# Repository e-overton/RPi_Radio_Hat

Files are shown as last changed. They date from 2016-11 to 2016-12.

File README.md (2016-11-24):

Raspberry Pi B+ Radio Hat
============================
This board adds two AWA24S 2.4GHz DSS radio modules to the Raspberry Pi to enable remote control using radio-controller-like standards. In addition a real time clock is added to the board to keep track of time in a battery powered project.

This proect is based on the RPi template from: https://github.com/xesscorp/RPi_Hat_Template

Note this board is in development, and has not been fabricated/tested.

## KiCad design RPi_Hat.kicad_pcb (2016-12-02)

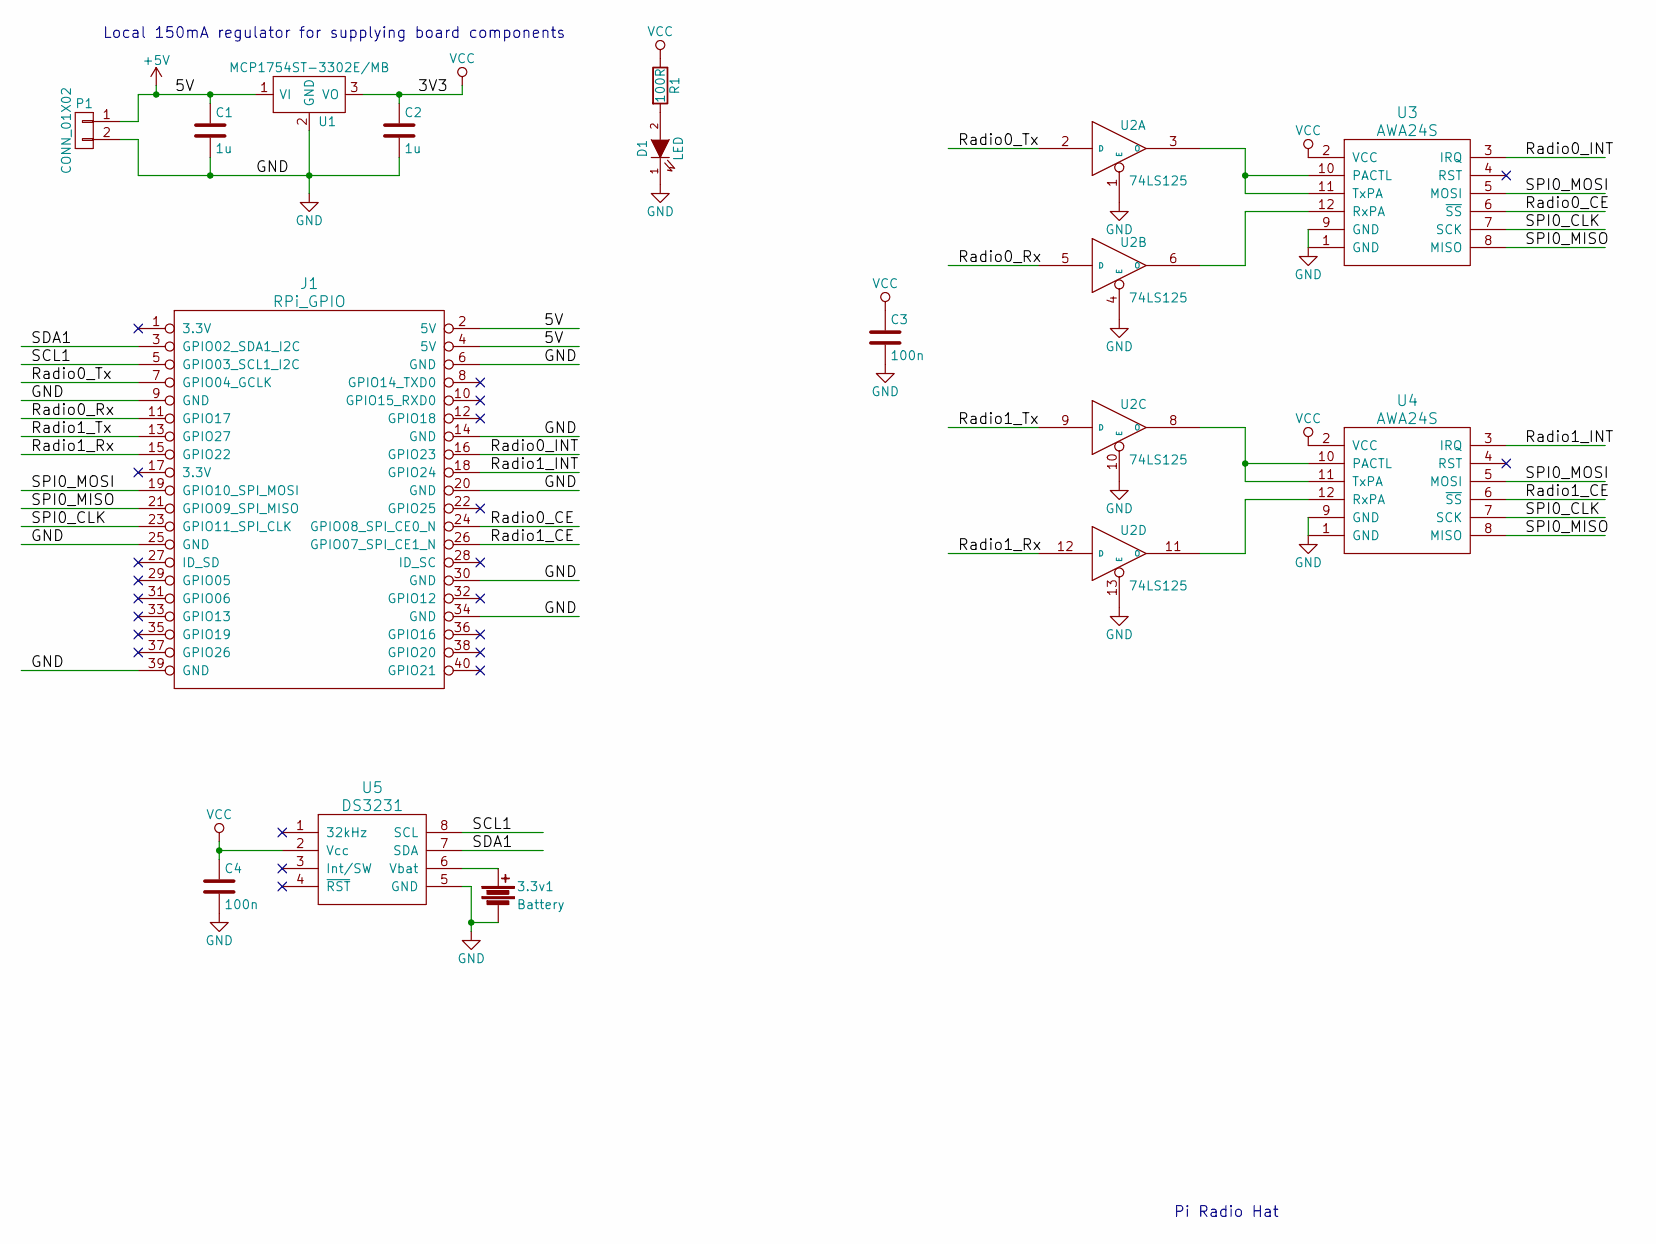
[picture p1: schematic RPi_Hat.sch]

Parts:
3.3v1: Battery; cr1225
C1, C2: 1u; C_1206
C3, C4: 100n; C_1206
D1: LED; LED_1206
J1: RPi_GPIO
P1: CONN_01X02; Pin_Header_Straight_1x02
R1: 100R; R_1206_HandSoldering
U1: MCP1754ST-3302E/MB; SOT-223
U2: 74LS125; SOIC-14_N
U3, U4: AWA24S
U5: DS3231; SOIC-8_3.9x4.9mm_Pitch1.27mm

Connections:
+5V: C1.1, J1.2 (5V), J1.4 (5V), P1.1, U1.1 (VI)
/Radio0_CE: J1.24 (GPIO08_SPI_CE0_N), U3.6 (~SS)
/Radio0_INT: J1.16 (GPIO23), U3.3 (IRQ)
/Radio0_Rx: J1.11 (GPIO17), U2.5 (D)
/Radio0_Tx: J1.7 (GPIO04_GCLK), U2.2 (D)
/Radio1_CE: J1.26 (GPIO07_SPI_CE1_N), U4.6 (~SS)
/Radio1_INT: J1.18 (GPIO24), U4.3 (IRQ)
/Radio1_Rx: J1.15 (GPIO22), U2.12 (D)
/Radio1_Tx: J1.13 (GPIO27), U2.9 (D)
/SCL1: J1.5 (GPIO03_SCL1_I2C), U5.8 (SCL)
/SDA1: J1.3 (GPIO02_SDA1_I2C), U5.7 (SDA)
/SPI0_CLK: J1.23 (GPIO11_SPI_CLK), U3.7 (SCK), U4.7 (SCK)
/SPI0_MISO: J1.21 (GPIO09_SPI_MISO), U3.8 (MISO), U4.8 (MISO)
/SPI0_MOSI: J1.19 (GPIO10_SPI_MOSI), U3.5 (MOSI), U4.5 (MOSI)
GND: 3.3v1.2, C1.2, C2.2, C3.2, C4.2, D1.1 (K), J1.6 (GND), J1.9 (GND), J1.14 (GND), J1.20 (GND), J1.25 (GND), J1.30 (GND), J1.34 (GND), J1.39 (GND), P1.2, U1.2 (GND), U1.4, U2.1 (E), U2.4 (E), U2.7 (GND), U2.10 (E), U2.13 (E), U3.1 (GND), U3.9 (GND), U4.1 (GND), U4.9 (GND), U5.5 (GND)
unnamed: 3.3v1.1, U5.6 (Vbat)
unnamed: D1.2 (A), R1.2
unnamed: U2.3 (O), U3.10 (PACTL), U3.11 (TxPA)
unnamed: U2.6 (O), U3.12 (RxPA)
unnamed: U2.8 (O), U4.10 (PACTL), U4.11 (TxPA)
unnamed: U2.11 (O), U4.12 (RxPA)
VCC: C2.1, C3.1, C4.1, R1.1, U1.3 (VO), U2.14 (VCC), U3.2 (VCC), U4.2 (VCC), U5.2 (Vcc)

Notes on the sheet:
Local 150mA regulator for supplying board components
Pi Radio Hat

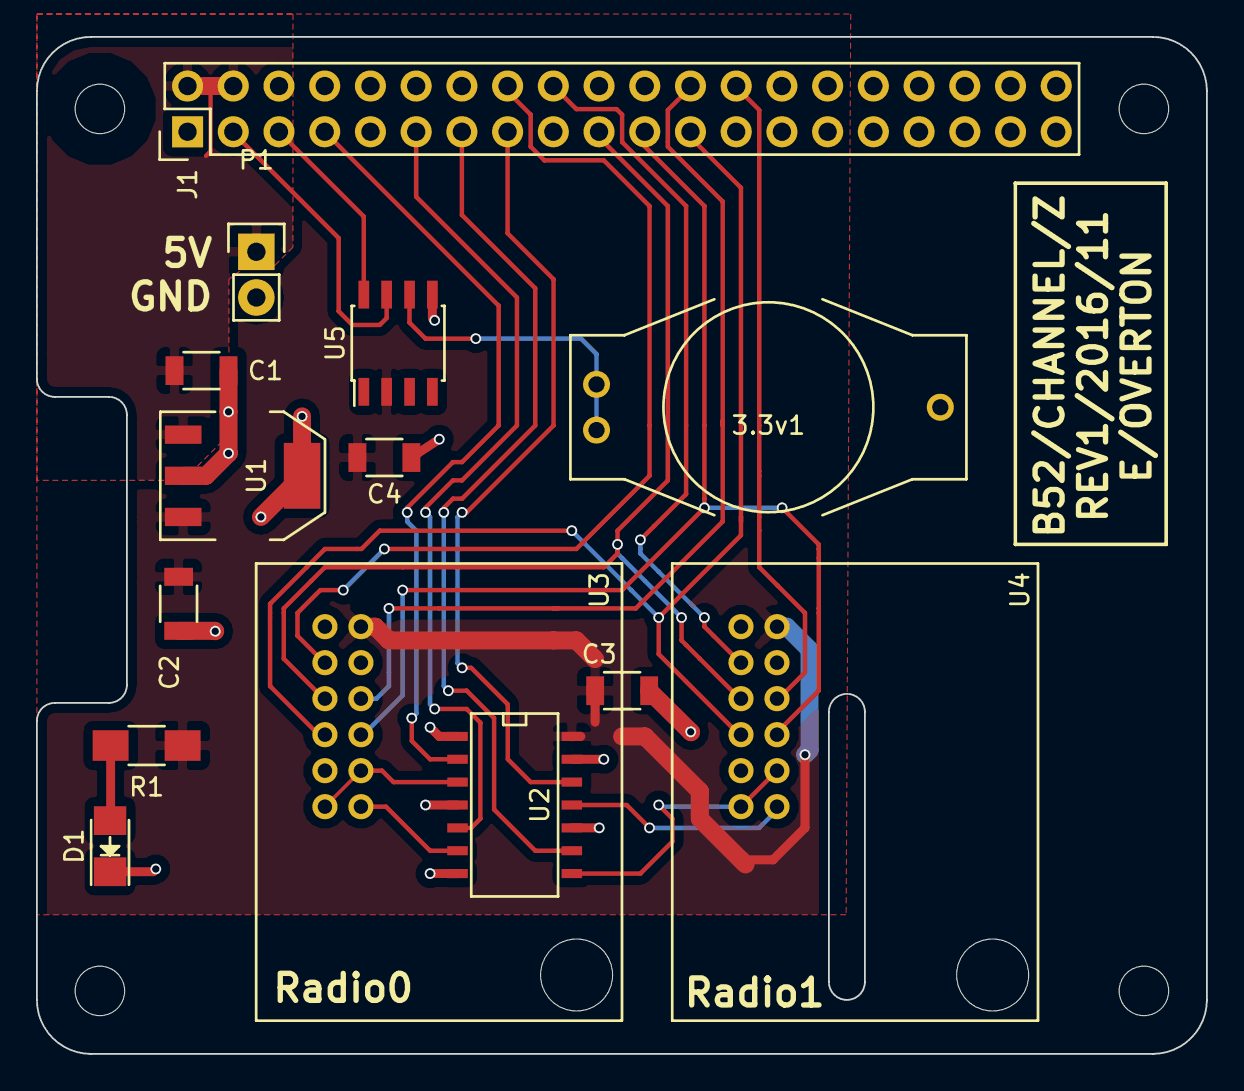
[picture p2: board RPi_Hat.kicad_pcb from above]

Board: 2 copper layers, 65.0 x 56.5 mm, 14 parts (0 on the bottom side), 22 nets.

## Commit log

2016-11-24 Hat modified to add AWA24S radios
    [RPi_GPIO.sch, RPi_Hat.sch, pihatmod.kicad_pcb]
2016-11-30 Revised name of PCB
    [RPi_Hat-B.Cu.gbr, RPi_Hat-B.Mask.gbr, RPi_Hat-Edge.Cuts.gbr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]
2016-12-02 first version to go to board house
    [RPi_Hat-B.Cu.gbl, RPi_Hat-B.Mask.gbs, RPi_Hat-Edge.Cuts.gm1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]
2016-12-02 cleanup of old files, First production version
    [RPi_Hat.kicad_pcb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]
